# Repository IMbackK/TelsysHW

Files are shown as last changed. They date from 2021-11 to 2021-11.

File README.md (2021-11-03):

# Telsys Hardware

Telsys is a small integrated wireless bluetooth low energy measurement amplifier and digitizer. Its primary intention is the use with strain gauges in sensor integrated structures. Sutch as the strain reporting pipe seen below. The firmware for the nrf52 used in this design can be found here: https://github.com/IMbackK/TelsysFW. A GUI client for reciveing the data as well as to examine the data can be found here: https://github.com/IMbackK/TelsysMaster

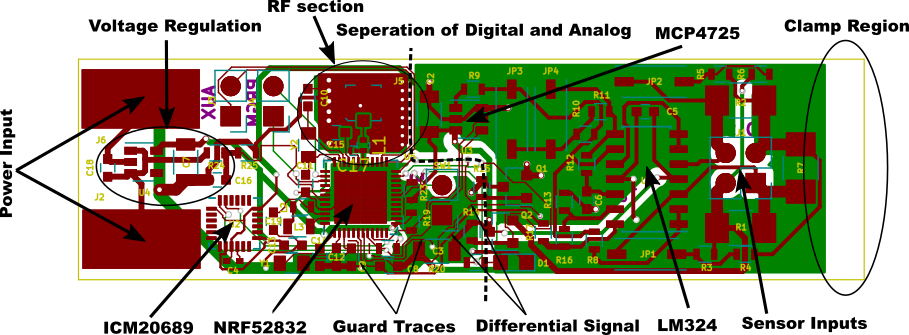
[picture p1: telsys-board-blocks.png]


These are kicad files detailing the shematic and board design of the Telsys device.
Kicad can be found here: https://www.kicad.org/

License: gpl-3.0 only, see license/GPL.txt

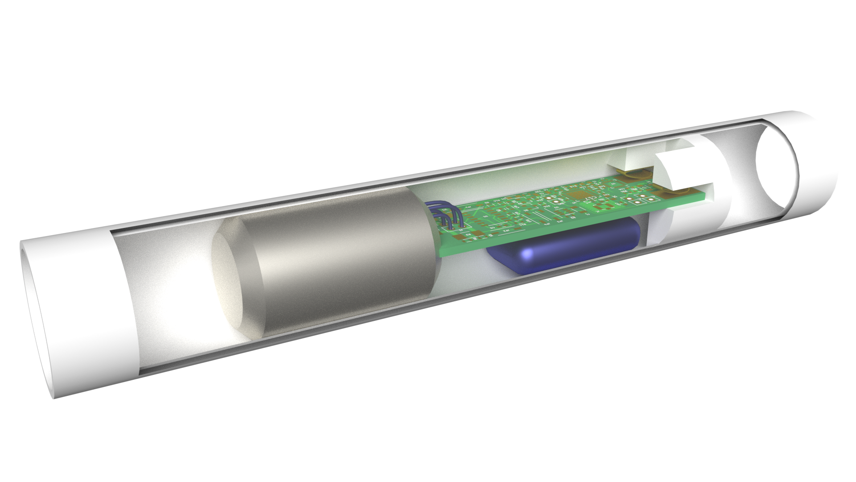
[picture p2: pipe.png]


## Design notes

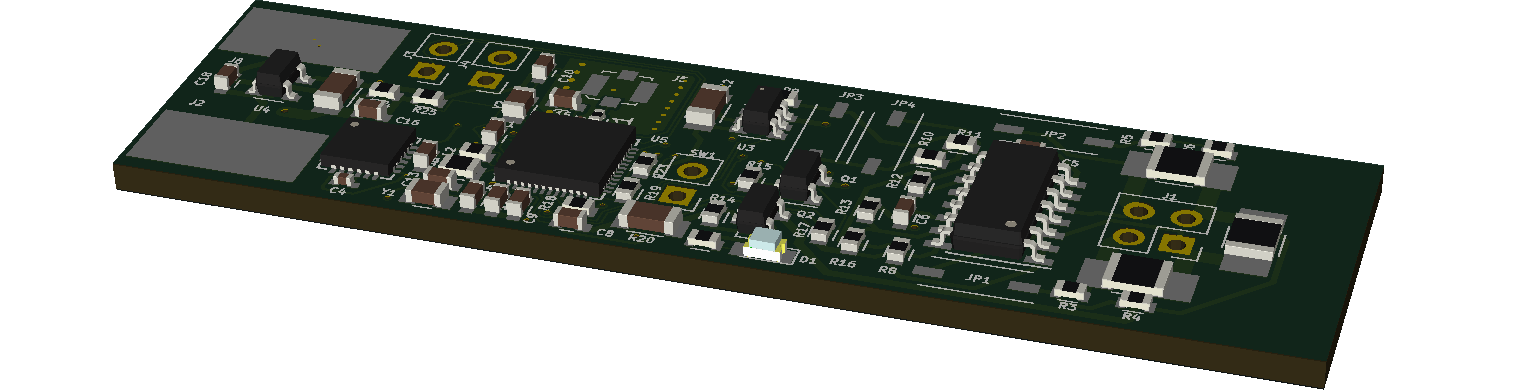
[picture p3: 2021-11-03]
telsys-board.png

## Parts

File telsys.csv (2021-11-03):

Reference | Value | Footprint | Type | Tolerance | Part Number
C13 | 1uF | Capacitors_SMD:C_0603 | Ceramic |  | Suggest
R8 | 560R | Resistors_SMD:R_0603 | Thin Film | 1.00% | Suggest
R9 | 68K | Resistors_SMD:R_0603 | Thin Film | 1.00% | Suggest
R10 | 150K | Resistors_SMD:R_0603 | Thin Film | 1.00% | Suggest
C5 | 1uF | Capacitors_SMD:C_0603 | Thin Film | 1.00% | Suggest
R19 | 1K | Resistors_SMD:R_0603 | Thin Film | 5% | Suggest
R18 | 1K | Resistors_SMD:R_0603 | Thin Film | 5% | Suggest
C8 | 1uF | Capacitors_SMD:C_0603 | Ceramic |  | Suggest
U1 | LM324A | Housings_SOIC:SOIC-14_3.9x8.7mm_Pitch1.27mm |  |  | LM324A
R12 | 5.6K | Resistors_SMD:R_0603 | Thin Film | 1.00% | Suggest
C6 | 1uF | Capacitors_SMD:C_0603 | Thin Film | 1.00% | Suggest
R17 | 5.6K | Resistors_SMD:R_0603 | Thin Film | 1.00% | Suggest
R13 | 10K | Resistors_SMD:R_0603 | Thin Film | 1.00% | Suggest
R16 | 10K | Resistors_SMD:R_0603 | Thin Film | 1.00% | Suggest
R15 | 100K | Resistors_SMD:R_0603 | Thin Film | 1.00% | Suggest
R5 | 100K | Resistors_SMD:R_0603 | Thin Film | 1.00% | Suggest
R6 | 100K | Resistors_SMD:R_0603 | Thin Film | 1.00% | Suggest
R4 | 100K | Resistors_SMD:R_0603 | Thin Film | 1.00% | Suggest
R3 | 100K | Resistors_SMD:R_0603 | Thin Film | 1.00% | Suggest
U2 | MPU9150 | Housings_DFN_QFN:QFN-24_4x4mm_Pitch0.5mm |  |  | MPU-9150
C3 | 10nF | Capacitors_SMD:C_1206 | Ceramic |  | Suggest
C1 | 2.2nF | Capacitors_SMD:C_0603 | Ceramic |  | Suggest
C4 | 0.1uF | Capacitors_SMD:C_0402_NoSilk | Ceramic |  | Suggest
U3 | MCP4725 | TO_SOT_Packages_SMD:SOT-23-6 |  |  | MCP4725A0T-E/CH
C2 | 10nF | Capacitors_SMD:C_1206 | Ceramic |  | Suggest
JP1 | Jumper_NO_Small | Buttons_Switches_SMD:SW_DIP_x1_W5.08mm_Slide_Copal_CHS-A |  |  | CHS-01TA
JP2 | Jumper_NO_Small | Buttons_Switches_SMD:SW_DIP_x1_W5.08mm_Slide_Copal_CHS-A |  |  | CHS-01TA
U5 | nrf52832-qfax | Housings_DFN_QFN:UQFN-48-1EP_6x6mm_Pitch0.4mm |  |  | nRF52832-QFAA-R7
R20 | 6.8k | Resistors_SMD:R_0603 | Thin Film | 5% | Suggest
Y1 | 32.768KHz | Capacitors_SMD:C_0805 | Ceramic |  | ABS06W-32.768kHz-J-2-T
C12 | 12pF | Capacitors_SMD:C_0603 | Ceramic |  | 02013A120GAT2A
C9 | 12pF | Capacitors_SMD:C_0603 | Ceramic |  | 02013A120GAT2A
C14 | 100nF | Capacitors_SMD:C_0603 | Ceramic |  | Suggest
J5 | Conn_Coaxial | Connectors_Molex:Molex_Microcoaxial_RF |  |  | 734120110
Y2 | 32MHz | Capacitors_SMD:C_0805 | Ceramic |  | ABS06W-32.768kHz-D-2-T
C10 | 12pF | Capacitors_SMD:C_0603 | Ceramic |  | 02013A120GAT2A
C11 | 12pF | Capacitors_SMD:C_0603 | Ceramic |  | 02013A120GAT2A
L1 | 3.9nH | Resistors_SMD:R_0402 | Thin Film | 1.00% | L04023R9BHNTR
C17 | 0.8pF | Capacitors_SMD:C_0201 | Ceramic |  | GJM0335C1ER80BB01D
C15 | 100pF | Capacitors_SMD:C_0603 | Ceramic |  | Suggest
D1 | LED_RED | LEDs:LED_0805 |  |  | Suggest
R23 | 10K | Resistors_SMD:R_0603 | Thin Film | 5% | Suggest
R14 | 100K | Resistors_SMD:R_0603 | Thin Film | 1.00% | Suggest
U4 | TLV70032_SOT23-5 | TO_SOT_Packages_SMD:SOT-23-5 |  |  | TLV70025QDDCRQ1
C18 | 1uF | Capacitors_SMD:C_0603 | Ceramic |  | Suggest
C7 | 10uF | Capacitors_SMD:C_1206 | Ceramic |  | Suggest
R11 | 300K | Resistors_SMD:R_0603 | Thin Film | 1.00% | Suggest
JP3 | JPC | Buttons_Switches_SMD:SW_DIP_x1_W5.08mm_Slide_Copal_CHS-A |  |  | CHS-01TA
JP4 | JPC | Buttons_Switches_SMD:SW_DIP_x1_W5.08mm_Slide_Copal_CHS-A |  |  | CHS-01TA
L3 | 10uH | Resistors_SMD:R_0805 | Thin Film | 1.00% | Suggest
L2 | 13nH | Resistors_SMD:R_0603 | Thin Film | 1.00% | Suggest
R24 | 10M | Resistors_SMD:R_0603 | Thin Film | 5% | Suggest
R25 | 10M | Resistors_SMD:R_0603 | Thin Film | 5% | Suggest
C16 | 1uf | Capacitors_SMD:C_0603 | Ceramic |  | Suggest
C19 | 1uF | Capacitors_SMD:C_0603 | Ceramic |  | Suggest
Q1 | Q_NMOS_GSD | TO_SOT_Packages_SMD:SOT-23 |  |  | NTR3A052PZT1G
Q2 | Q_PMOS_GSD | TO_SOT_Packages_SMD:SOT-23 |  |  | STR2P3LLH6

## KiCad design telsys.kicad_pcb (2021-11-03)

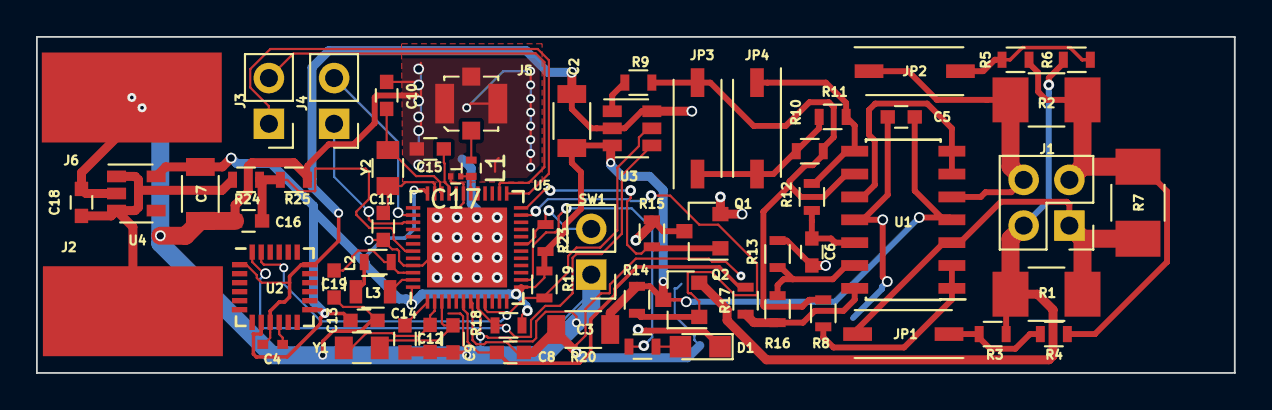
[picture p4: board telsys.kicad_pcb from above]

Board: 2 copper layers, 66.5 x 18.7 mm, 65 parts (0 on the bottom side), 43 nets.

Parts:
C2, C3: 10nF; C_1206
C4: 0.47uF; C_0402_NoSilk
C5, C6, C8, C13, C18, C19: 1uF; C_0603
C7: 10uF; C_1206
C9, C10, C11, C12: 12pF; C_0603
C14: 100nF; C_0603
C15: 100pF; C_0603
C16: 1uf; C_0603
C17: 0.8pF; C_0201
D1: LED_RED; LED_0805
J1: Conn_02x02_Odd_Even; Pin_Header_Straight_2x02_Pitch2.54mm
J2: INPUTV; SolderWirePad_single_SMD_5x10mm
J3: PRGM; Pin_Header_Straight_1x02_Pitch2.54mm
J4: UART; Pin_Header_Straight_1x02_Pitch2.54mm
J5: Conn_Coaxial; Molex_Microcoaxial_RF
J6: INPUTGND; SolderWirePad_single_SMD_5x10mm
JP1, JP2: Jumper_NO_Small; SW_DIP_x1_W5.08mm_Slide_Copal_CHS-A
JP3, JP4: JPC; SW_DIP_x1_W5.08mm_Slide_Copal_CHS-A
L1: 3.9nH; R_0402
L2: 13nH; R_0603
L3: 10uH; R_0805
Q1: Q_NMOS_GSD; SOT-23
Q2: Q_PMOS_GSD; SOT-23
R1, R2, R7: R; R_1210_HandSoldering
R3, R4, R5, R6, R14, R15: 100K; R_0603
R8: 560R; R_0603
R9: 68K; R_0603
R10: 150K; R_0603
R11: 300K; R_0603
R12, R17: 5.6K; R_0603
R13, R16, R23: 10K; R_0603
R18, R19: 1K; R_0603
R20: 6.8k; R_0603
R24, R25: 10M; R_0603
SW1: SW_Push; Pin_Header_Straight_1x02_Pitch2.54mm
U1: LM324A; SOIC-14_3.9x8.7mm_Pitch1.27mm
U2: ICM20689; QFN-24_4x4mm_Pitch0.5mm
U3: MCP4725; SOT-23-6
U4: TLV70032_SOT23-5; SOT-23-5
U5: nrf52832-qfax; UQFN-48-1EP_6x6mm_Pitch0.4mm
Y1: 32.768KHz; C_0805
Y2: 32MHz; C_0805

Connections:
NRFGND: C7.2, C9.2, C10.2, C11.2, C12.2, C13.1, C14.1, C15.1, C16.2, C17.2, C18.2, C19.2, D1.1, J5.2, J6.1, Q1.3, R15.1, R25.1, SW1.1, U4.2, U5.31, U5.45, U5.49
unnamed: C4.1, U2.10
unnamed: C6.2, R12.2, U1.12
unnamed: C8.2, R17.2, U5.6
unnamed: C9.1, U5.3, Y1.2
unnamed: C10.1, U5.34, Y2.1
unnamed: C11.1, U5.35, Y2.2
unnamed: C12.1, U5.2, Y1.1
unnamed: C14.2, U5.1
unnamed: C15.2, U5.33
unnamed: C16.1, R24.1, R25.2, U5.43
unnamed: C17.1, L1.2, U5.30
unnamed: C18.1, J2.1, R24.2, U4.1, U4.3
unnamed: C19.1, L2.1, U5.46
unnamed: D1.2, R20.1
unnamed: J1.1, JP1.2, R1.2, R7.1, U1.3
unnamed: J1.4, JP2.1, R2.1, U1.5
unnamed: J3.1, U5.25
unnamed: J3.2, U5.26
unnamed: J4.1, U5.39
unnamed: J4.2, U5.38
unnamed: J5.1, L1.1
unnamed: JP1.1, R3.1, R4.2
unnamed: JP2.2, R5.2, R6.1
unnamed: JP3.1, JP4.2, R10.1, R11.2
unnamed: JP3.2, R8.2, R9.1, R10.2, U1.9
unnamed: JP4.1, R11.1, R12.1, U1.8
unnamed: L2.2, L3.1
unnamed: L3.2, U5.47
unnamed: Q1.1, R15.2, U5.24
unnamed: Q2.1, R14.2, U5.23
unnamed: R8.1, U1.1, U1.2
unnamed: R9.2, U3.1
unnamed: R13.2, R16.1, U1.13
unnamed: R16.2, R17.1, U1.14
unnamed: R20.2, U5.14
unnamed: R23.2, SW1.2, U5.19
unnamed: U1.6, U1.7, U1.10
SCL: R19.2, U2.23, U3.5, U5.9
SDA: R18.2, U2.24, U3.4, U5.8
VCC: C2.1, C3.1, C5.1, C7.1, C13.2, Q2.3, R14.1, R18.1, R19.1, R23.1, U1.4, U2.8, U2.13, U3.3, U4.5, U5.13, U5.36, U5.48
VGND: C2.2, C3.2, C4.2, C5.2, C6.1, C8.1, J1.3, Q1.2, R2.2, R4.1, R5.1, R7.2, R13.1, U1.11, U2.9, U2.18, U3.2, U3.6, U5.7
VSG: J1.2, Q2.2, R1.1, R3.2, R6.2
